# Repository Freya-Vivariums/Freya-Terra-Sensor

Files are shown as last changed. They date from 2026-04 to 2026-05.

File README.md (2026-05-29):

Freya banner

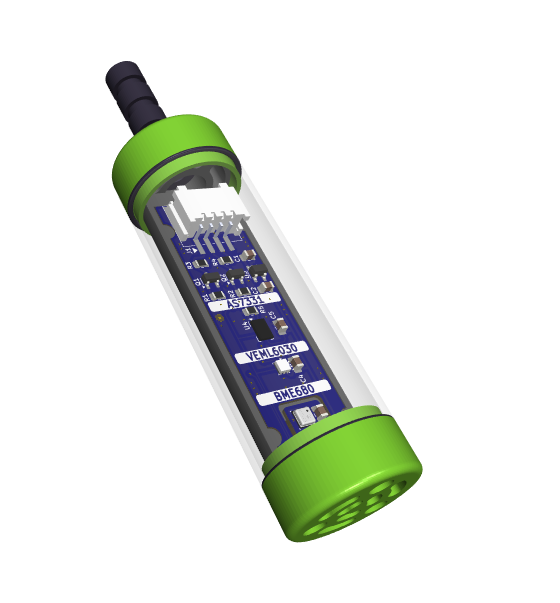
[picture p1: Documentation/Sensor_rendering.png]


The **Freya Terra Sensor** is the control system's eyes and ears within the vivarium - the hardware that enables measurement of environmental conditions experienced by the inhabitants of the vivarium.

#### Measurement capabilities:
- Temperature
- Relative air humidity
- Barometric pressure
- Air quality (VOC)
- Ambient light (visible spectrum)
- UVA/UVB/UVC (spectral 220-400nm)

<br clear="right"/>

## Hardware
Designed with **[KiCad](https://www.kicad.org/download/)**, the Freya Terra Sensor's electronic hardware is a curated collection of high-end integrated circuit sensors for comprehensive environmental monitoring.

- Bosch **BME680** (**0x76**): Integrated environmental sensor combining **temperature**, **humidity**, **barometric pressure**, and VOC gas sensing for **air quality** monitoring. **[Datasheet](https://www.bosch-sensortec.com/media/boschsensortec/downloads/datasheets/bst-bme680-ds001.pdf)**
- Vishay **VEML6030** (**0x10**): High-accuracy **ambient light** sensor with spectral response matching the human eye for precise lux measurement and photoperiod management. **[Datasheet](https://www.vishay.com/docs/84366/veml6030.pdf)**
- ams OSRAM **AS7331** (**0x74**): Three-channel **spectral UV** sensor with separated UVA, UVB, and UVC detection for UV bulb monitoring and safety verification. **[Datasheet](https://look.ams-osram.com/m/1856fd2c69c35605/original/AS7331-Spectral-UVA-B-C-Sensor.pdf)**
- Microchip **MIC5225-3.3YM5**: The sensor module operates internally at 3.3V but accepts 5V input for improved noise immunity over longer cable runs. The on-board voltage regulator provides clean 3.3V power to all sensor ICs, while a bi-directional level shifter handles I²C communication between the 5V bus and 3.3V sensors.
- The **JST PH 2.0mm 4-Pin connector** allows for easy replacement of the board.

> [!NOTE]  
> The PCB is finished with a coating for resisting the humid conditions.

## Enclosure
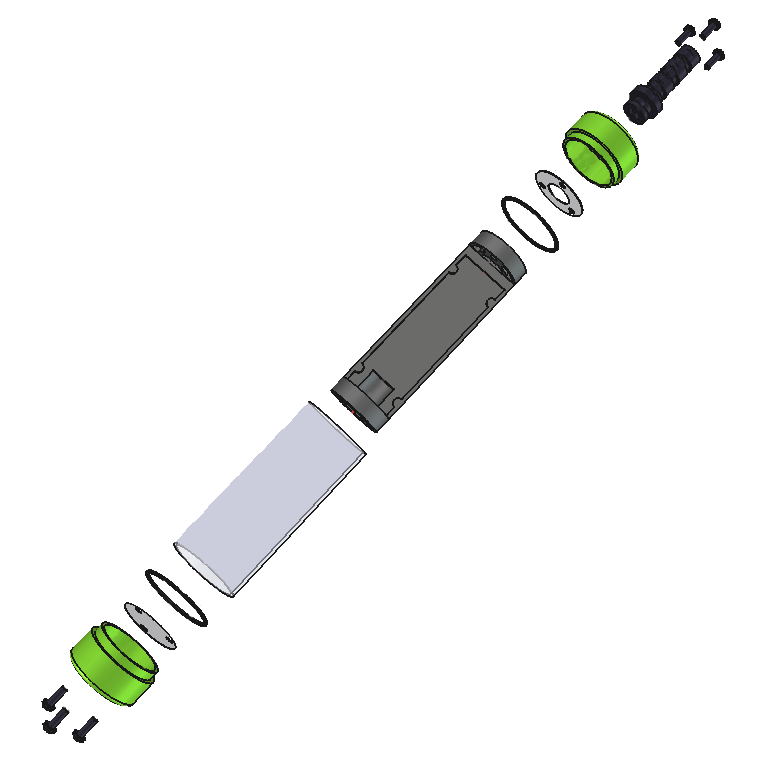
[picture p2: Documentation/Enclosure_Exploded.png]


The sensor's enclosure is designed in **[FreeCAD](https://www.freecad.org/downloads.php?lang=en)**. It protects the sensitive equipment from the challenges of the environment within the vivarium. The **quartz tube** provides full-spectrum light transparency for spectral measurements while **mesh-filtered ventilation** in the end caps enables air exchange for sensing. The internal holder positions the PCB and facilitates assembly.

<br clear="right"/>

## Software
The sensor driver is a TypeScript/Node.js application that runs as a systemd service on Linux/Debian systems. It provides sensor readings via D-Bus for integration with the Freya Vivarium Control System Node-RED application.

#### Installation
When installing the Freya system, the sensor driver is automatically installed. For manual installation:

```bash
wget -O install.sh https://github.com/Freya-Vivariums/Freya-terra-sensor/releases/latest/download/install.sh
chmod +x ./install.sh
sudo ./install.sh
```

The service runs automatically and can be monitored with:
```bash
systemctl status freya.sensor.terra.service
journalctl -u freya.sensor.terra.service -f
```

#### D-Bus Interface
Applications interact with the sensor via D-Bus on the system bus:
- **Service:** `freya.sensor.terra`
- **Path:** `/freya/sensor/terra`
- **Signals:** `measurement(variable: string, value: string)` - Emits readings for temperature, humidity, pressure, light, UVA, UVB, and UVC

## License & Collaboration
**Copyright© 2024-2026 Sanne 'SpuQ' Santens**. The hardware and enclosure are released under the [**CERN OHL-W**](Hardware/LICENSE.txt) license. The software is released under the [**GNU GPL-3.0**](Software/LICENSE.txt) license. [Trademark rules](https://github.com/Freya-Vivariums/.github/blob/main/brand/Freya_Trademark_Rules_and_Guidelines.md) apply to the Freya™ brand.

### Collaboration

If you'd like to contribute to this project, please follow these guidelines:
1. Fork the repository and create your branch from `main`.
2. Make your changes and ensure they adhere to the project's design style and conventions.
3. Test your changes thoroughly.
4. Ensure your commits are descriptive and well-documented.
5. Open a pull request, describing the changes you've made and the problem or feature they address.

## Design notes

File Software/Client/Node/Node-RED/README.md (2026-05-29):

Freya Banner



**[Node-RED](https://nodered.org/)** is a visual programming tool that lets you wire together hardware, APIs, and online services by connecting blocks in a flow-based editor. The **Freya Terra Sensor** Node-RED node brings environmental sensor data from the Freya Terra Sensor directly into your Node-RED flows over D-Bus.

<br clear="right"/>



## Installation
#### Node-RED flow editor
Navigate to `Settings > Manage Palette`, then in the `Install` tab, search for `@freya-vivariums/freya-terra-sensor-node-red-contrib` and click the `Install` button.

#### Manually using NPM
On your device, navigate to the Node-RED folder (on a Freya system, it's at `/opt/Freya/nodered`), and run:
```
npm install @freya-vivariums/freya-terra-sensor-node-red-contrib
```

## Node: Freya Terra Sensor
Connects to the `freya.sensor.terra` D-Bus service and emits measurement messages into your flow. Configure which environment variable to receive (`temperature`, `humidity`, `pressure`, `light`, etc.) or select **All measurements** to receive every reading.

## License & Collaboration
**Copyright© 2025 Sanne 'SpuQ' Santens**. This project is licensed under the **[MIT License](LICENSE.txt)**. The [Rules & Guidelines](https://github.com/Freya-Vivariums/.github/blob/main/brand/Freya_Trademark_Rules_and_Guidelines.md) apply to the usage of the Freya Vivariums™ brand.

### Collaboration
If you'd like to contribute to this project, please follow these guidelines:
1. Fork the repository and create your branch from `main`.
2. Make your changes and ensure they adhere to the project's coding style and conventions.
3. Test your changes thoroughly.
4. Ensure your commits are descriptive and well-documented.
5. Open a pull request, describing the changes you've made and the problem or feature they address.

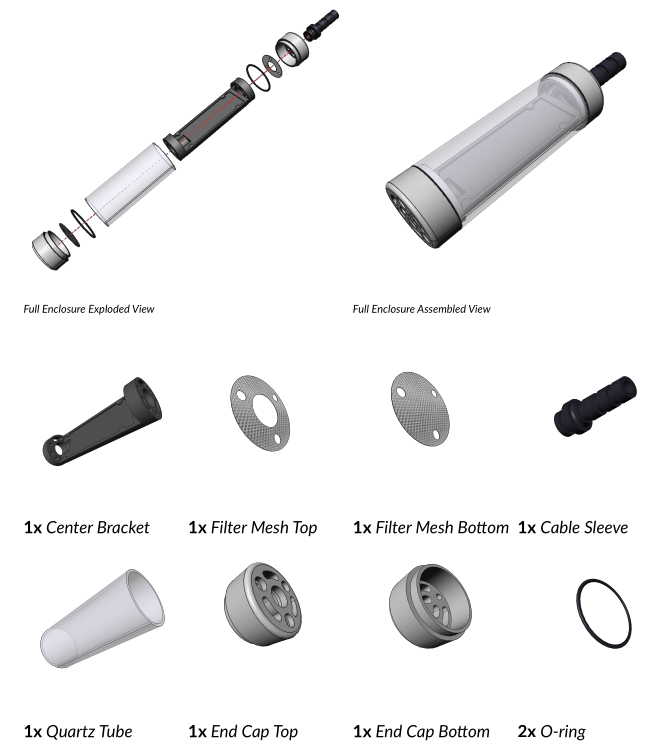
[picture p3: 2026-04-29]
Documentation/Enclosure_rendering.png

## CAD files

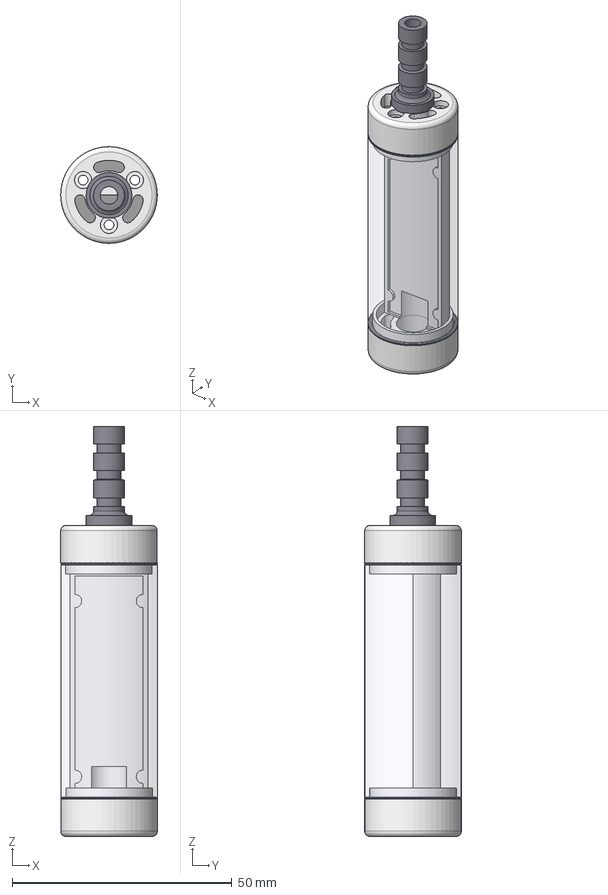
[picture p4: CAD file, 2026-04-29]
Enclosure/Enclosure.step
22.0 x 22.0 x 93.3 mm
EndCap_Top
Mesh_Top
RubberRing_Top
Center
QuartzTube
EndCap_Bottom
Mesh_Bottom
RubberRing_Bottom
CableProtector

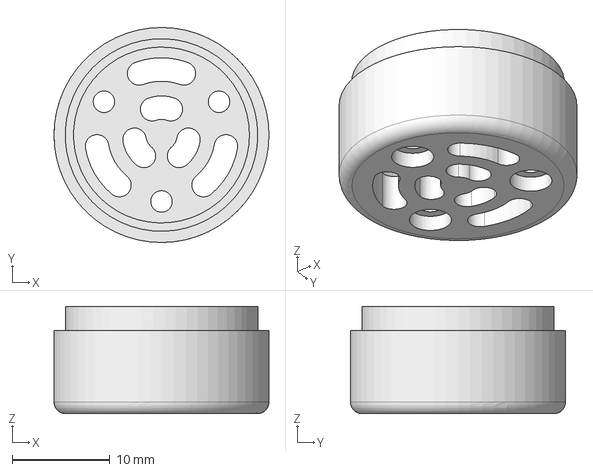
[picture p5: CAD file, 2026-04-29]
Enclosure/Enclosure-EndCap_Bottom.step
22.0 x 22.0 x 11.0 mm

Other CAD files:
Enclosure/Enclosure-EndCap_Top.step
Enclosure/Enclosure.FCStd

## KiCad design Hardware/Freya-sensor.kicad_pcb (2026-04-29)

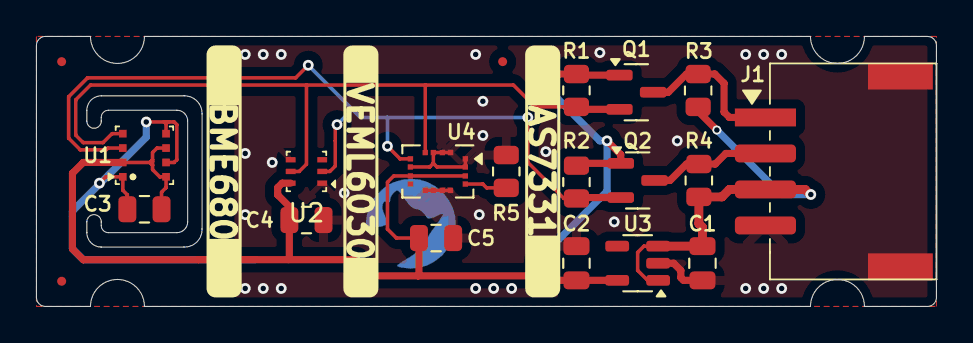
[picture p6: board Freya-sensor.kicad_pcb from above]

Board: 2 copper layers, 50.0 x 15.0 mm, 17 parts (0 on the bottom side), 8 nets.

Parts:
C1, C2: 10uF; C_0805_2012Metric
C3, C4, C5: 100nF; C_0805_2012Metric
J1: Grove; Grove_SMD_right_angle
Q1, Q2: BS170; SOT-23
R1, R2, R3, R4: 10k; R_0805_2012Metric
R5: 3M3; R_0805_2012Metric
U1: BME680
U2: VEML6030
U3: MIC5225-3.3YM5; SOT-23-5
U4: AS7331; Osram_AS7331

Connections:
+3V3: C2.1, C3.1, C4.1, C5.1, Q1.1 (G), Q2.1 (G), R1.1, R2.1, U1.2 (CSB), U1.6 (VDDIO), U1.8 (VDD), U2.6 (VDD), U3.5 (OUT), U4.3 (VDDA), U4.10 (VDDD)
+5V: C1.1, J1.3, R3.1, R4.1, U3.1 (IN), U3.3 (EN)
GND: C1.2, C2.2, C3.2, C4.2, C5.2, J1.4, J1.5, R5.2, U1.1 (GND), U1.5 (SDO), U1.7 (GND), U2.1 (GND), U2.4 (ADDR), U3.2 (GND), U4.1 (VSSA), U4.2 (VSSA), U4.5 (VSSA), U4.6 (VSSA), U4.7 (A1), U4.8 (SYN), U4.11 (VSSD), U4.14 (A0), U4.15 (VSSA), U4.16 (VSSA)
unnamed: R5.1, U4.4 (REXT)
SCL: Q1.2 (S), R1.2, U1.4 (SCK), U2.5 (SCL), U4.13 (SCL)
SCL_5v: J1.1, Q1.3 (D), R3.2
SDA: Q2.2 (S), R2.2, U1.3 (SDI), U2.2 (SDA), U4.12 (SDA)
SDA_5v: J1.2, Q2.3 (D), R4.2

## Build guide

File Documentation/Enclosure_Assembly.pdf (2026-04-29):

## Freya “Terra” Sensor - Enclosure Assembly

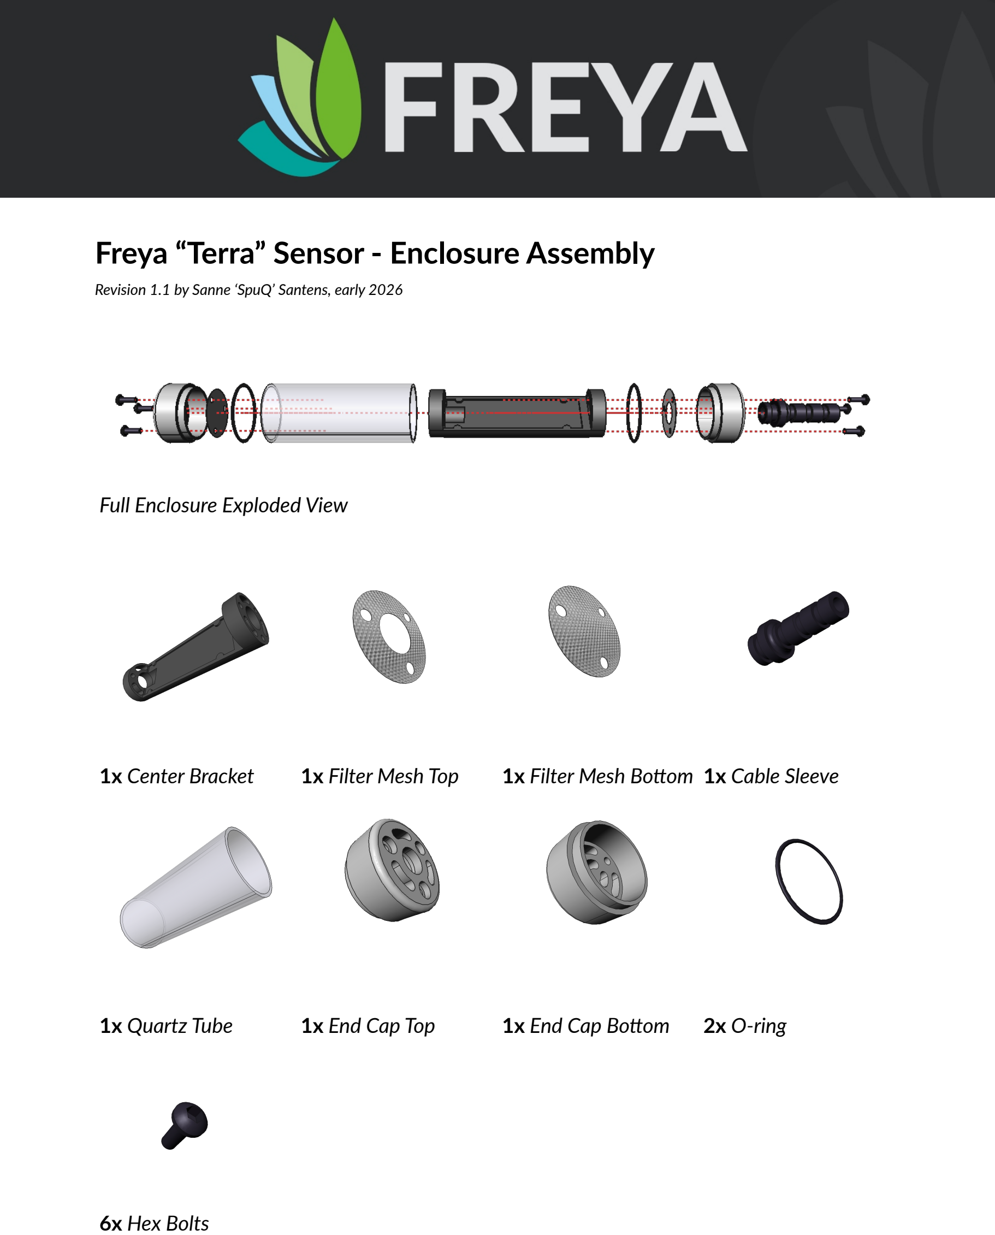
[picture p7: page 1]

Revision 1.1 by Sanne ‘SpuQ’ Santens, early 2026

Full Enclosure Exploded View

1x Center Bracket | 1x Filter Mesh Top | 1x Filter Mesh Bottom 1x Cable Sleeve
1x Quartz Tube | 1x End Cap Top | 1x End Cap Bottom | 2x O-ring

6x Hex Bolts

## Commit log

2026-02-10 Software: AS7331 driver improvements
2026-03-13 Update enclosure
    [Enclosure-EndCap_Bottom.step, Enclosure-EndCap_Top.step, Enclosure.FCStd]
2026-03-16 Enclosure center corrections
    [Enclosure.FCStd]
2026-03-17 Enclosure: Center ventilation channel
    [Enclosure.FCStd]
2026-03-17 Enclosure: PCB cutout
    [Enclosure.FCStd, Freya-sensor.kicad_pcb]
2026-03-19 Enclosure: cable protector
    [Enclosure.FCStd]
2026-03-19 Sensor enclosure model update
    [Enclosure.step, Freya-sensor.kicad_pcb]
2026-03-19 Documentation: Sensor rendering update
2026-03-24 Enclosure: assembly documentation
    [Enclosure.FCStd]
2026-03-25 Enclosure: included the bolts
    [Enclosure.FCStd]
2026-04-13 Enclosure: Mesh Mask
    [Enclosure.FCStd]
2026-04-16 Documentation: sensor rendering
2026-04-16 Enclosure coloring
    [Enclosure.FCStd, Freya-sensor.kicad_pcb]
2026-04-17 Documentation: Enclosure exploded image
2026-04-29 Driver: light precision
2026-04-29 Driver: auto-range implementation
2026-04-29 Driver: AS7331 auto-range implementation + bugfixes
2026-04-29 Driver: light sensor auto-range improvements
2026-04-29 Driver: deploy local
2026-05-29 Software: Node-RED Sensor Measurement Node rename
2026-07-02 Gas Resistance
2026-08-11 Bugfix: enable I2C on the device
2026-10-02 Enclosure: Mechanical documentation
2026-10-11 Hardware: include enclosure 3D model in documentation
2026-10-11 Documentation: enclosure exploded view
2026-10-11 Software: gitignore for the driver
2026-10-30 Enclosure: filter techdraw for manufacturing
